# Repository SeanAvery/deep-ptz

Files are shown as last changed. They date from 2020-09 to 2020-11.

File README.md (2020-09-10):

# deep-ptz

## Materials

1. Jetson Nano Developer Kit Board
2. Sony IMX219 Camera Board with Arducam Verifocal IR Cut Lens
3. Arducam Verifocal and Pan/Tilt Board
4. Control Angle180 Metal Gear Digital High Speed Torque Servo
5. Long CSI Ribbon Cable
6. 3D printable pant/tilt kit

## Procedure

1. Apply shader to adjust for lens vignette

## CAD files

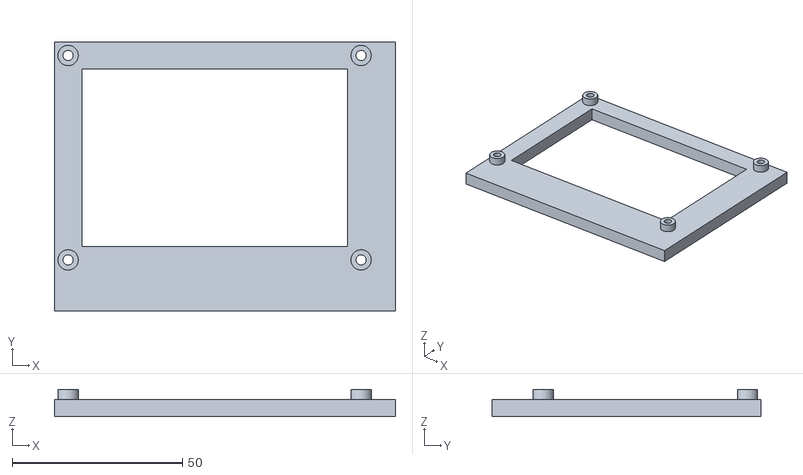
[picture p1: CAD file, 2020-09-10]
stl/jetson_nano_mount_v1.stl
100.1 x 79.0 x 8.00

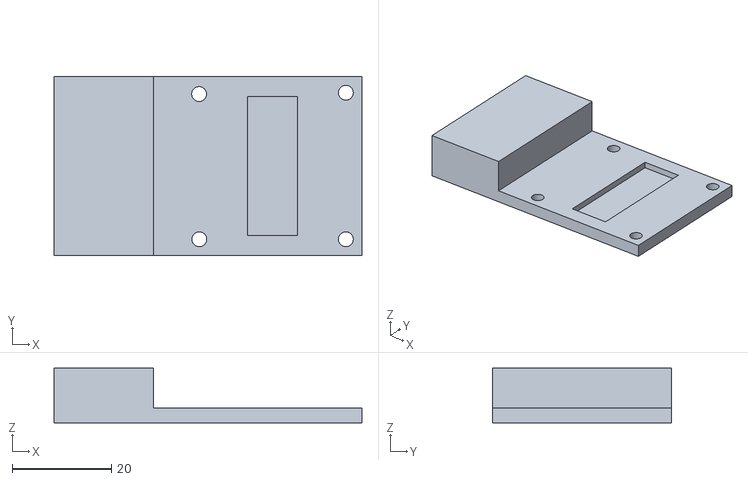
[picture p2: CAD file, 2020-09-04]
stl/arducam_verifocal_cameraboard_mount.stl
62.0 x 36.0 x 11.0

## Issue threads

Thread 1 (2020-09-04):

PTZ control board I2C connection

SeanAvery, 2020-09-04:
Board Components:

1. [Panasonic Lens Controller](https://www.mouser.com/new/panasonicec/panasonicec-an41908a/)
2. [ARM Cortex MCU](https://www.st.com/en/microcontrollers-microprocessors/stm32f030f4.html)

SeanAvery, 2020-10-01:
Had a problem with faulty I2C Bus on Jetson Nano Development board.

Ordered a new one which fixed the problem.

Forum thread can be found here:

https://forums.developer.nvidia.com/t/i2c-bus-1-broken-on-jetson-nano/154654

Closed 2020-10-01.

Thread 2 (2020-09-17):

Control Servos from Motor Control Board

SeanAvery, 2020-09-17:
Control Board:
HiLetgo PCA9685 16 Channel 12-Bit PWM Servo Motor Driver IIC Module for Arduino Robot

SeanAvery, 2020-09-17:
### damn, somehow corrupted my i2c 1 bus.

i2cdetect -y -r 1 is slow (around 3 seconds per address). Cannot detect the i2c address of the control board.

SeanAvery, 2020-09-17:
https://forums.developer.nvidia.com/t/i2c-bus-1-broken-on-jetson-nano/154654

SeanAvery, 2020-09-17:
https://learn.adafruit.com/16-channel-pwm-servo-driver/hooking-it-up

SeanAvery, 2020-09-17:
## 5V Power Supply for Servos

So I have a 5V VCC that powers the pmw servo board but I still need another 5V V+ connection to drive the micro-servos!

### Solution 1
Even though the docs explicitly recommend not powering the servos from the board, why not try.

This actually works.

SeanAvery, 2020-09-17:
## Circuit Python Servo Kit Docs

https://circuitpython.readthedocs.io/projects/servokit/en/latest/

SeanAvery, 2020-10-01:
Works using 5V GPIO pin on dev board : )

Closed 2020-10-01.

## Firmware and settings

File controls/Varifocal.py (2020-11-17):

import sys
import time
class Focuser:
    bus = None
    CHIP_I2C_ADDR = 0x0C
    BUSY_REG_ADDR = 0x04
    starting_point = [
        11000, 10000, 10000, 
        10000, 10000, 9800, 
        9600, 9000, 8500, 
        8000, 7000, 6000, 
        5000, 3500, 2000, 
        0, 0, 0, 0
    ]
    end_point = [
        18000, 18000, 18000, 
        18000, 18000, 18000, 
        18000, 17500, 17500, 
        16500, 16000, 15000, 
        14000, 12500, 11000, 
        9500, 7500, 5000, 4000
    ]
    def __init__(self,bus):
        try:
            import smbus
            self.bus = smbus.SMBus(bus)
        except:
            sys.exit(0)
        
    def read(self,chip_addr,reg_addr):
        value = self.bus.read_word_data(chip_addr,reg_addr)
        value = ((value & 0x00FF)<< 8) | ((value & 0xFF00) >> 8)
        return value
    def write(self,chip_addr,reg_addr,value):
        if value < 0:
            value = 0
        value = ((value & 0x00FF)<< 8) | ((value & 0xFF00) >> 8)
        return self.bus.write_word_data(chip_addr,reg_addr,value)
    def isBusy(self):
        return self.read(self.CHIP_I2C_ADDR,self.BUSY_REG_ADDR) != 0
    def waitingForFree(self):
        count = 0
        begin = time.time()
        while self.isBusy() and count < (5 / 0.01):
            count += 1
            time.sleep(0.01)
        # if count >= (5 / 0.01):
        #     print "wait timeout."
        # elif count != 0:
        #     print "wait time = %lf"%(time.time() - begin)

    OPT_BASE    = 0x1000
    OPT_FOCUS   = OPT_BASE | 0x01
    OPT_ZOOM    = OPT_BASE | 0x02
    OPT_MOTOR_X = OPT_BASE | 0x03
    OPT_MOTOR_Y = OPT_BASE | 0x04
    OPT_IRCUT   = OPT_BASE | 0x05
    opts = {
        OPT_FOCUS : {
            "REG_ADDR" : 0x01,
            "MAX_VALUE": 18000,
            "RESET_ADDR": 0x01 + 0x0A,
        },
        OPT_ZOOM  : {
            "REG_ADDR" : 0x00,
            "MAX_VALUE": 18000,
            "RESET_ADDR": 0x00 + 0x0A,
        },
        OPT_MOTOR_X : {
            "REG_ADDR" : 0x05,
            "MAX_VALUE": 180,
            "RESET_ADDR": None,
        },
        OPT_MOTOR_Y : {
            "REG_ADDR" : 0x06,
            "MAX_VALUE": 180,
            "RESET_ADDR": None,
        },
        OPT_IRCUT : {
            "REG_ADDR" : 0x0C, 
            "MAX_VALUE": 0x01,   #0x0001 open, 0x0000 close
            "RESET_ADDR": None,
        }
    }
    def reset(self,opt,flag = 1):
        self.waitingForFree()
        info = self.opts[opt]
        if info == None or info["RESET_ADDR"] == None:
            return
        self.write(self.CHIP_I2C_ADDR,info["RESET_ADDR"],0x0000)
        if flag & 0x01 != 0:
            self.waitingForFree()

    def get(self,opt,flag = 0):
        self.waitingForFree()
        info = self.opts[opt]
        return self.read(self.CHIP_I2C_ADDR,info["REG_ADDR"])

    def set(self,opt,value,flag = 1):
        self.waitingForFree()
        info = self.opts[opt]
        if value > info["MAX_VALUE"]:
            value = info["MAX_VALUE"]
        self.write(self.CHIP_I2C_ADDR,info["REG_ADDR"],value)
        if flag & 0x01 != 0:
            self.waitingForFree()
    def move(self, cmd, counter):
        print('hit move:', cmd)
        # zoom in
        val = 0
        if cmd == 0:
            val = self.get(self.OPT_ZOOM) + counter
            if val > 18000:
                val = 18000
            print('val', val)
            self.set(self.OPT_ZOOM, val)
        # zoom out
        if cmd == 1:
            val = self.get(self.OPT_ZOOM) - counter
            if val < 0:
                val = 0
            self.set(self.OPT_ZOOM, val)
        # focus in
        if cmd == 2:
            val = self.get(self.OPT_FOCUS) + counter
            if val > 18000:
                val = 18000
            self.set(self.OPT_FOCUS, val)
        # focus out
        if cmd == 3:
            val = self.get(self.OPT_FOCUS) - counter
            if val < 0:
                val = 0
            self.set(self.OPT_FOCUS, val)
        print('val', val)

pass 


def test():
    focuser = Focuser(1)
    focuser.reset(Focuser.OPT_FOCUS)
    focuser.reset(Focuser.OPT_ZOOM)
    # sys.exit(0)
    # while focuser.get(Focuser.OPT_FOCUS) < 18000:
    #     focuser.set(Focuser.OPT_FOCUS,focuser.get(Focuser.OPT_FOCUS) + 50)
    # focuser.set(Focuser.OPT_FOCUS,0)
    # focuser.set(Focuser.OPT_FOCUS, 12000)
    # focuser.set(Focuser.OPT_ZOOM, 12000)
    import random
    import time
    while True:
        focuser.move(random.randint(0, 3))

pass

if __name__ == "__main__":
    test()

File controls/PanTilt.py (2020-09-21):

import time
import sys
from adafruit_servokit import ServoKit

kit = ServoKit(channels=16)

def tilt_up():
  for i in range(0, 40, 2):
    kit.servo[0].angle = i
    time.sleep(0.01)

def pan_clockwise():
  for i in range(0, 180, 2):
    kit.servo[1].angle = i
    time.sleep(0.01)

def tilt_down():
  for i in reversed(range(0, 40, 2)):
    kit.servo[0].angle = i
    time.sleep(0.01)

def pan_counter():
  for i in reversed(range(0, 180, 2)):
    kit.servo[1].angle = i
    time.sleep(0.01)

kit.servo[0].angle = 0
kit.servo[1].angle = 0

while(True):
  pan_clockwise()
  tilt_up()
  pan_counter()
  tilt_down()
  

sys.exit()

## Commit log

2020-09-04 add prototype camera board to tripod mount
    [arducam_verifocal_cameraboard_mount.stl]
2020-09-10 init nano mount bracket
    [jetson_nano_mount_v1.stl]
2020-09-29 connecting to i2c bus 1
2020-09-30 simple camera capture
2020-09-30 laplacian of frame and calc mean
